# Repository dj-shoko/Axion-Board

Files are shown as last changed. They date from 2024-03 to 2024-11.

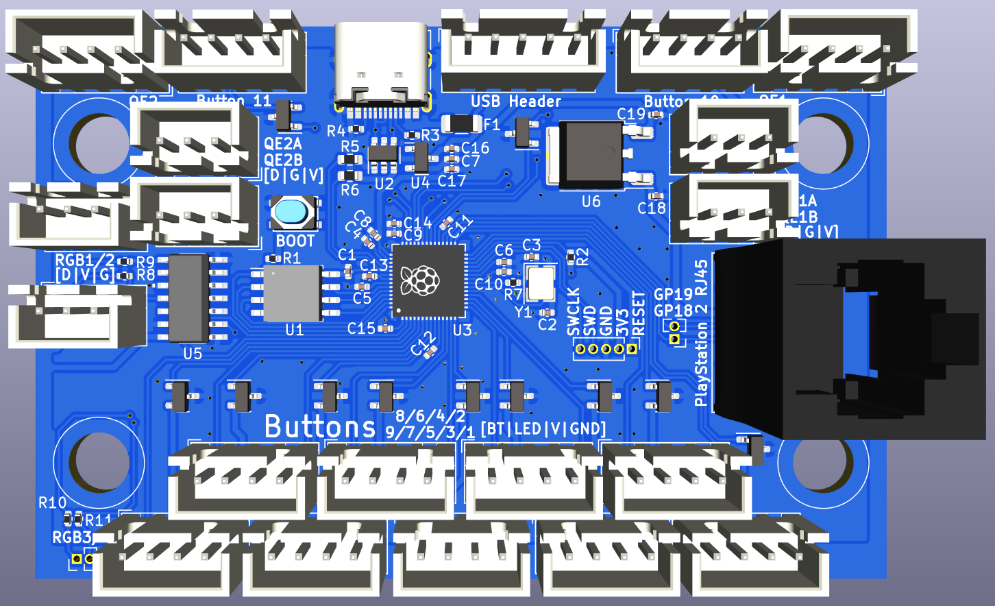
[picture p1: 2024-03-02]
images/render.png

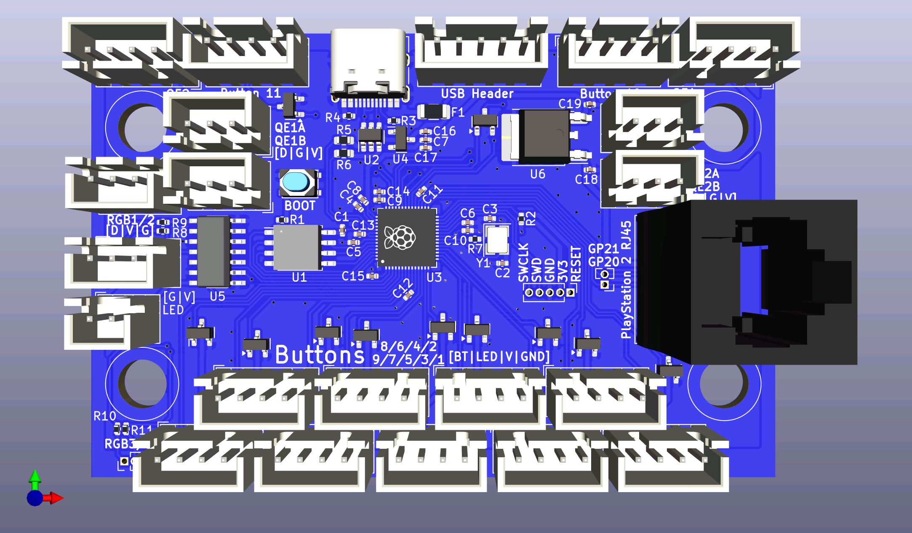
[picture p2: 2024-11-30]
images/render.jpg

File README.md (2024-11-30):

# Information
Fully functionally working PCB utilizing the RP2040 MCU with all GPIO pins broken out and able to be utilized. Main purpose of the board is for usage in beatmania IIDX and Sound Voltex controllers. The PCB can be dropped into DJ DAO based beatmania IIDX controllers as a drop in replacement, utilizing the same pin layout as their original PCBs. Main functionality allows for the usage of 11 buttons, 11 5V LEDs, 2 RGB pins, and 2 quadrature encoders (analog should also be accepted in theory due to those being hooked up to all 4 analog pins). PS2 support should be possible as well on the current PCB, but untested at the moment. Two extra pins are also available either for RGB or other general purposes if needed.

# Render and Schematics
- [Current board render](images/render.png)
- [Current board schematics](images/schematics.jpg)

# Credits
- [RP2040-designguide](https://github.com/Sleepdealr/RP2040-designguide/tree/main) to get started on the PCB designing aspects and schematics.
- [Pico Game Controller Firmware](https://github.com/speedypotato/Pico-Game-Controller) by SpeedyPotato for quick sanity check.
- [USBemani](https://github.com/progmem/usbemani) by Progmem for the current firmware I'm using for this board. Personally forked firmware UF2 files [here](https://github.com/dj-shoko/usbemani/releases).

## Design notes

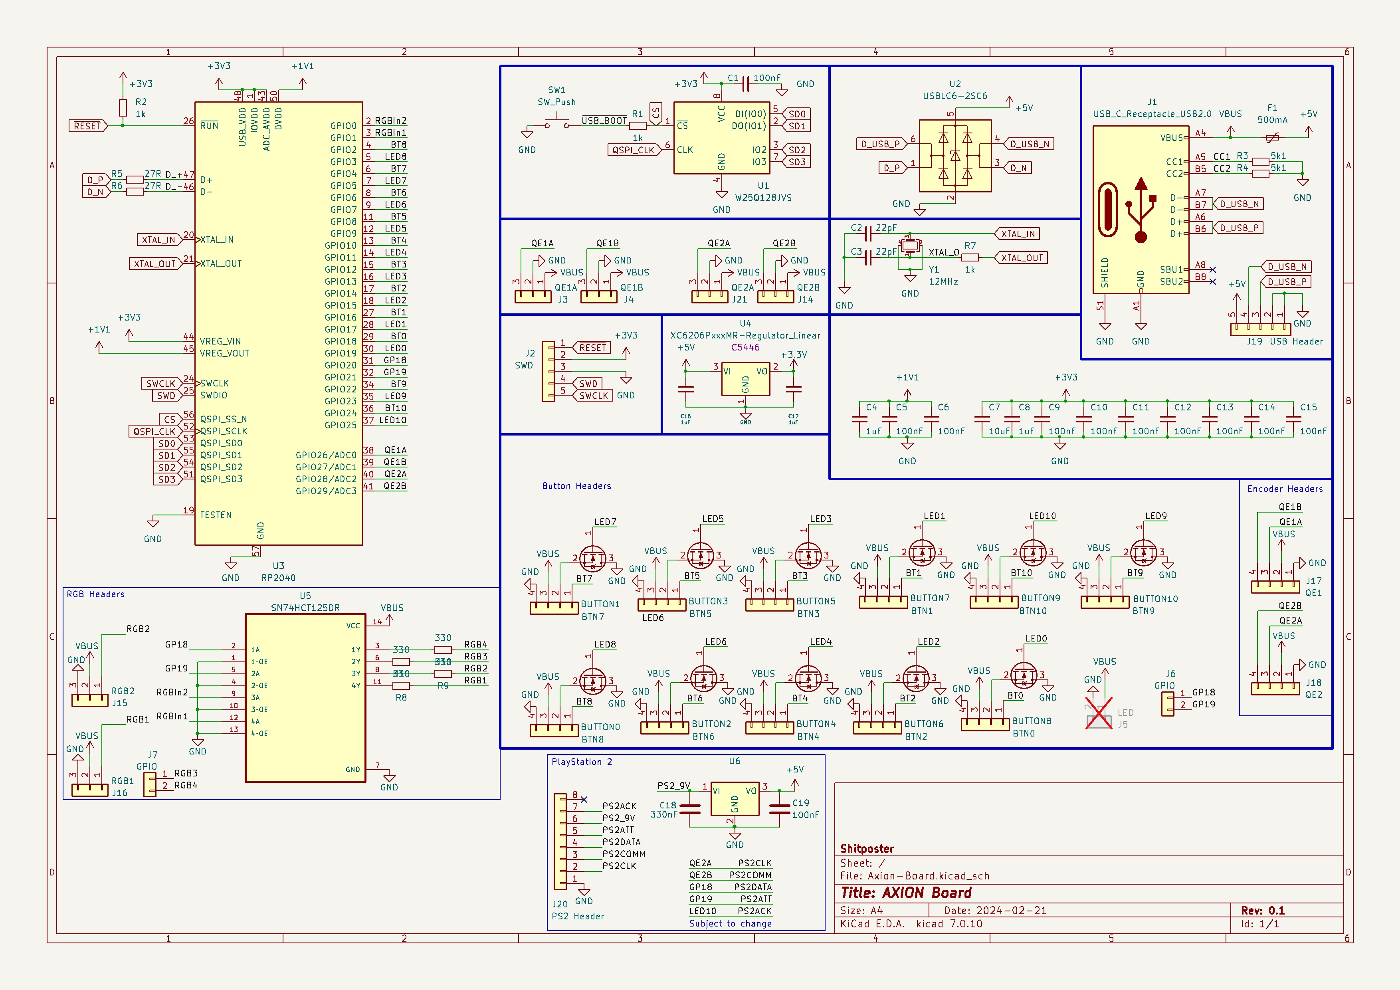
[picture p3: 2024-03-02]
images/schematics.jpg

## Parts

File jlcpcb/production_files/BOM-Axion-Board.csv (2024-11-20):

Comment | Designator | Footprint | LCSC
BSS138 | Q1,Q10,Q11,Q2,Q3,Q4,Q5,Q6,Q7,Q8,Q9 | SOT-23 | C112239
1k | R1,R2,R7 | R_0402_1005Metric | C11702
330 | R10,R11,R8,R9 | R_0402_1005Metric | C12246
W25Q128JVS | U1 | SOIC-8_5.23x5.23mm_P1.27mm | C131025
QE2B | J14,J15,J16,J21,J3,J4 | JST_XH_B3B-XH-A_1x03_P2.50mm_Vertical | C144394
BUTTON8 | BTN0,BTN1,BTN10,BTN2,BTN3,BTN4,BTN5,BTN6,BTN7,BTN8,BTN9,J17,J18 | JST_XH_B4B-XH-A_1x04_P2.50mm_Vertical | C144395
100nF | C1,C10,C11,C12,C13,C14,C15,C19,C5,C6,C9 | C_0402_1005Metric | C1525
10uF | C7 | C_0402_1005Metric | C15525
15pF | C2,C3 | C_0402_1005Metric | C1555
USB Header | J19 | JST_XH_B5B-XH-A_1x05_P2.50mm_Vertical | C157991
USB_C_Receptacle_USB2.0 | J1 | USB_C_Receptacle_HRO_TYPE-C-31-M-12 | C165948
RP2040 | U3 | RP2040-QFN-56 | C2040
SW_Push | SW1 | SW_SPST_PTS810 | C221895
27R | R5,R6 | R_0603_1608Metric | C25190
5k1 | R3,R4 | R_0402_1005Metric | C25905
USBLC6-2SC6 | U2 | SOT-23-6 | C2827654
PS2 Header | J20 | RJ45_OST_PJ012-8P8CX_Vertical | C2902702
330nF | C18 | C_0402_1005Metric | C307420
78M05_TO252-3 | U6 | TO-252-2 | C347278
SN74HCT125DR | U5 | SN74HCT125DR | C352957
1uF | C16,C17,C4,C8 | C_0402_1005Metric | C52923
XC6206PxxxMR-Regulator_Linear | U4 | SOT-23 | C5446
500mA | F1 | Fuse_1206_3216Metric | C70076
12MHz | Y1 | Crystal_SMD_3225-4Pin_3.2x2.5mm | C9002

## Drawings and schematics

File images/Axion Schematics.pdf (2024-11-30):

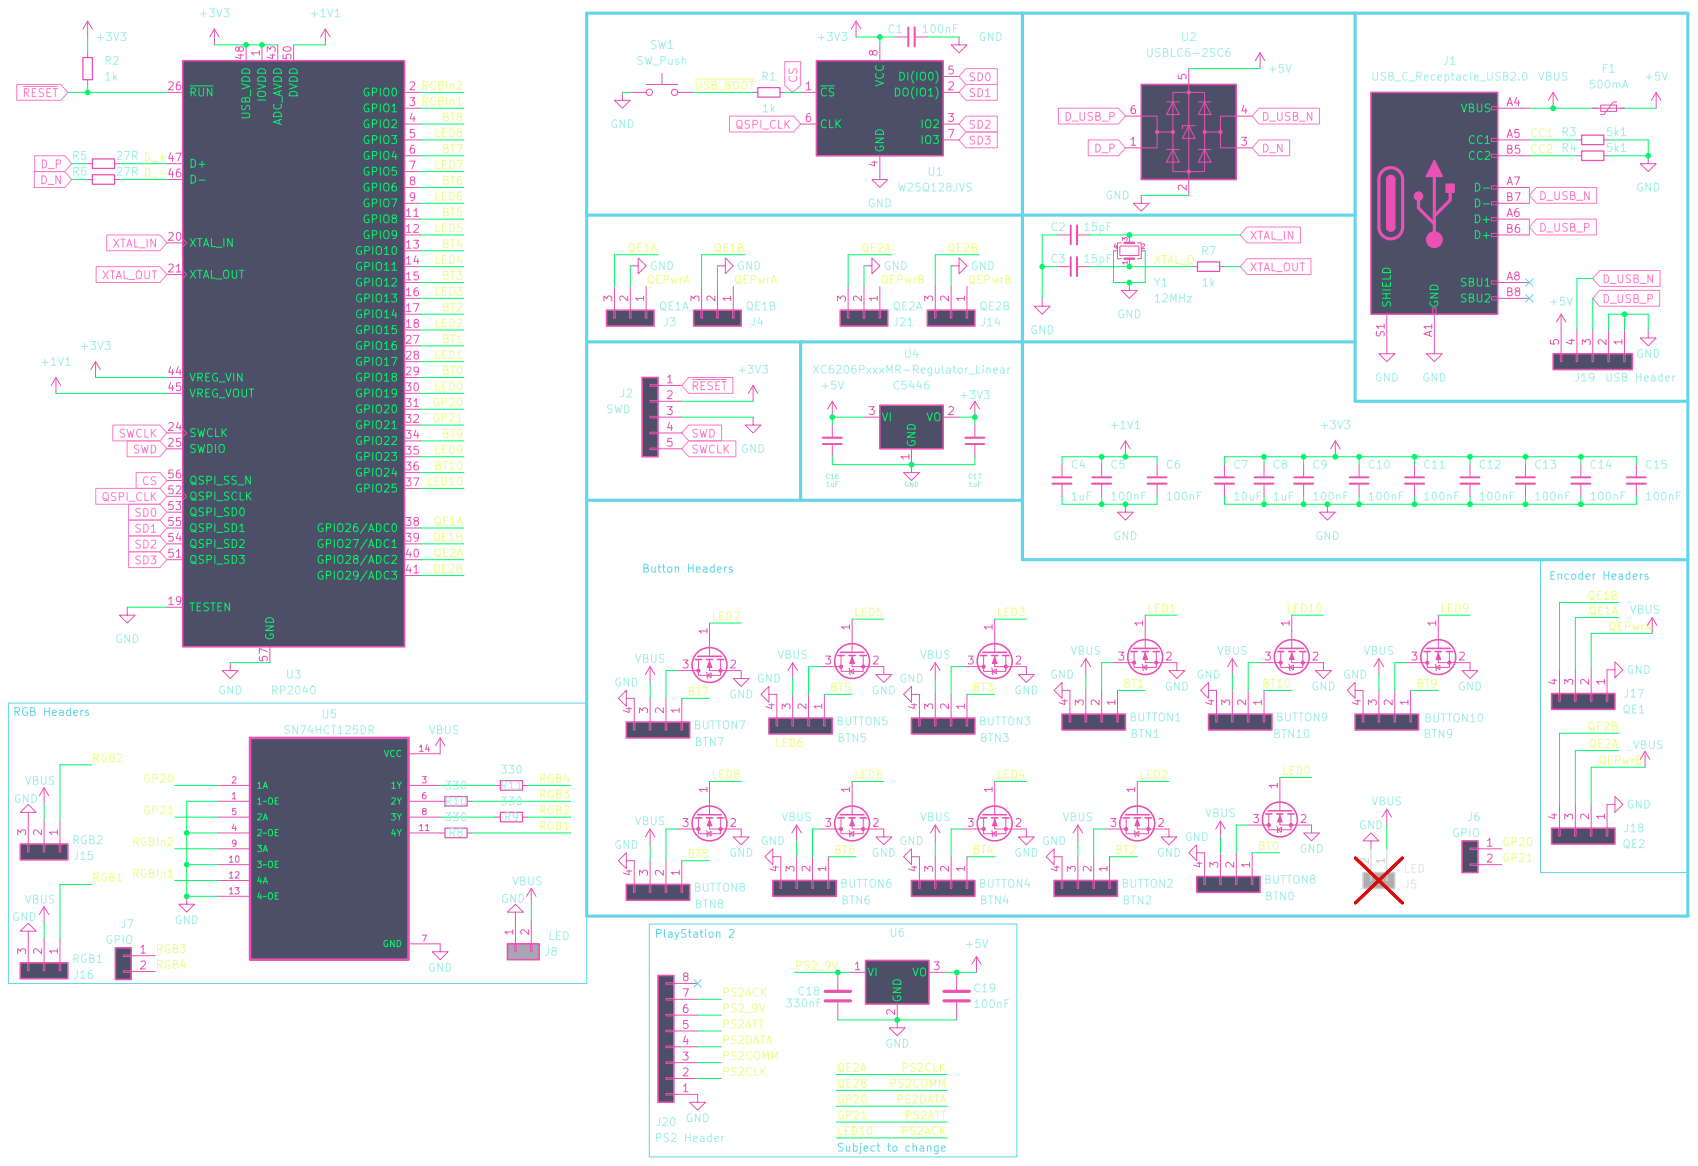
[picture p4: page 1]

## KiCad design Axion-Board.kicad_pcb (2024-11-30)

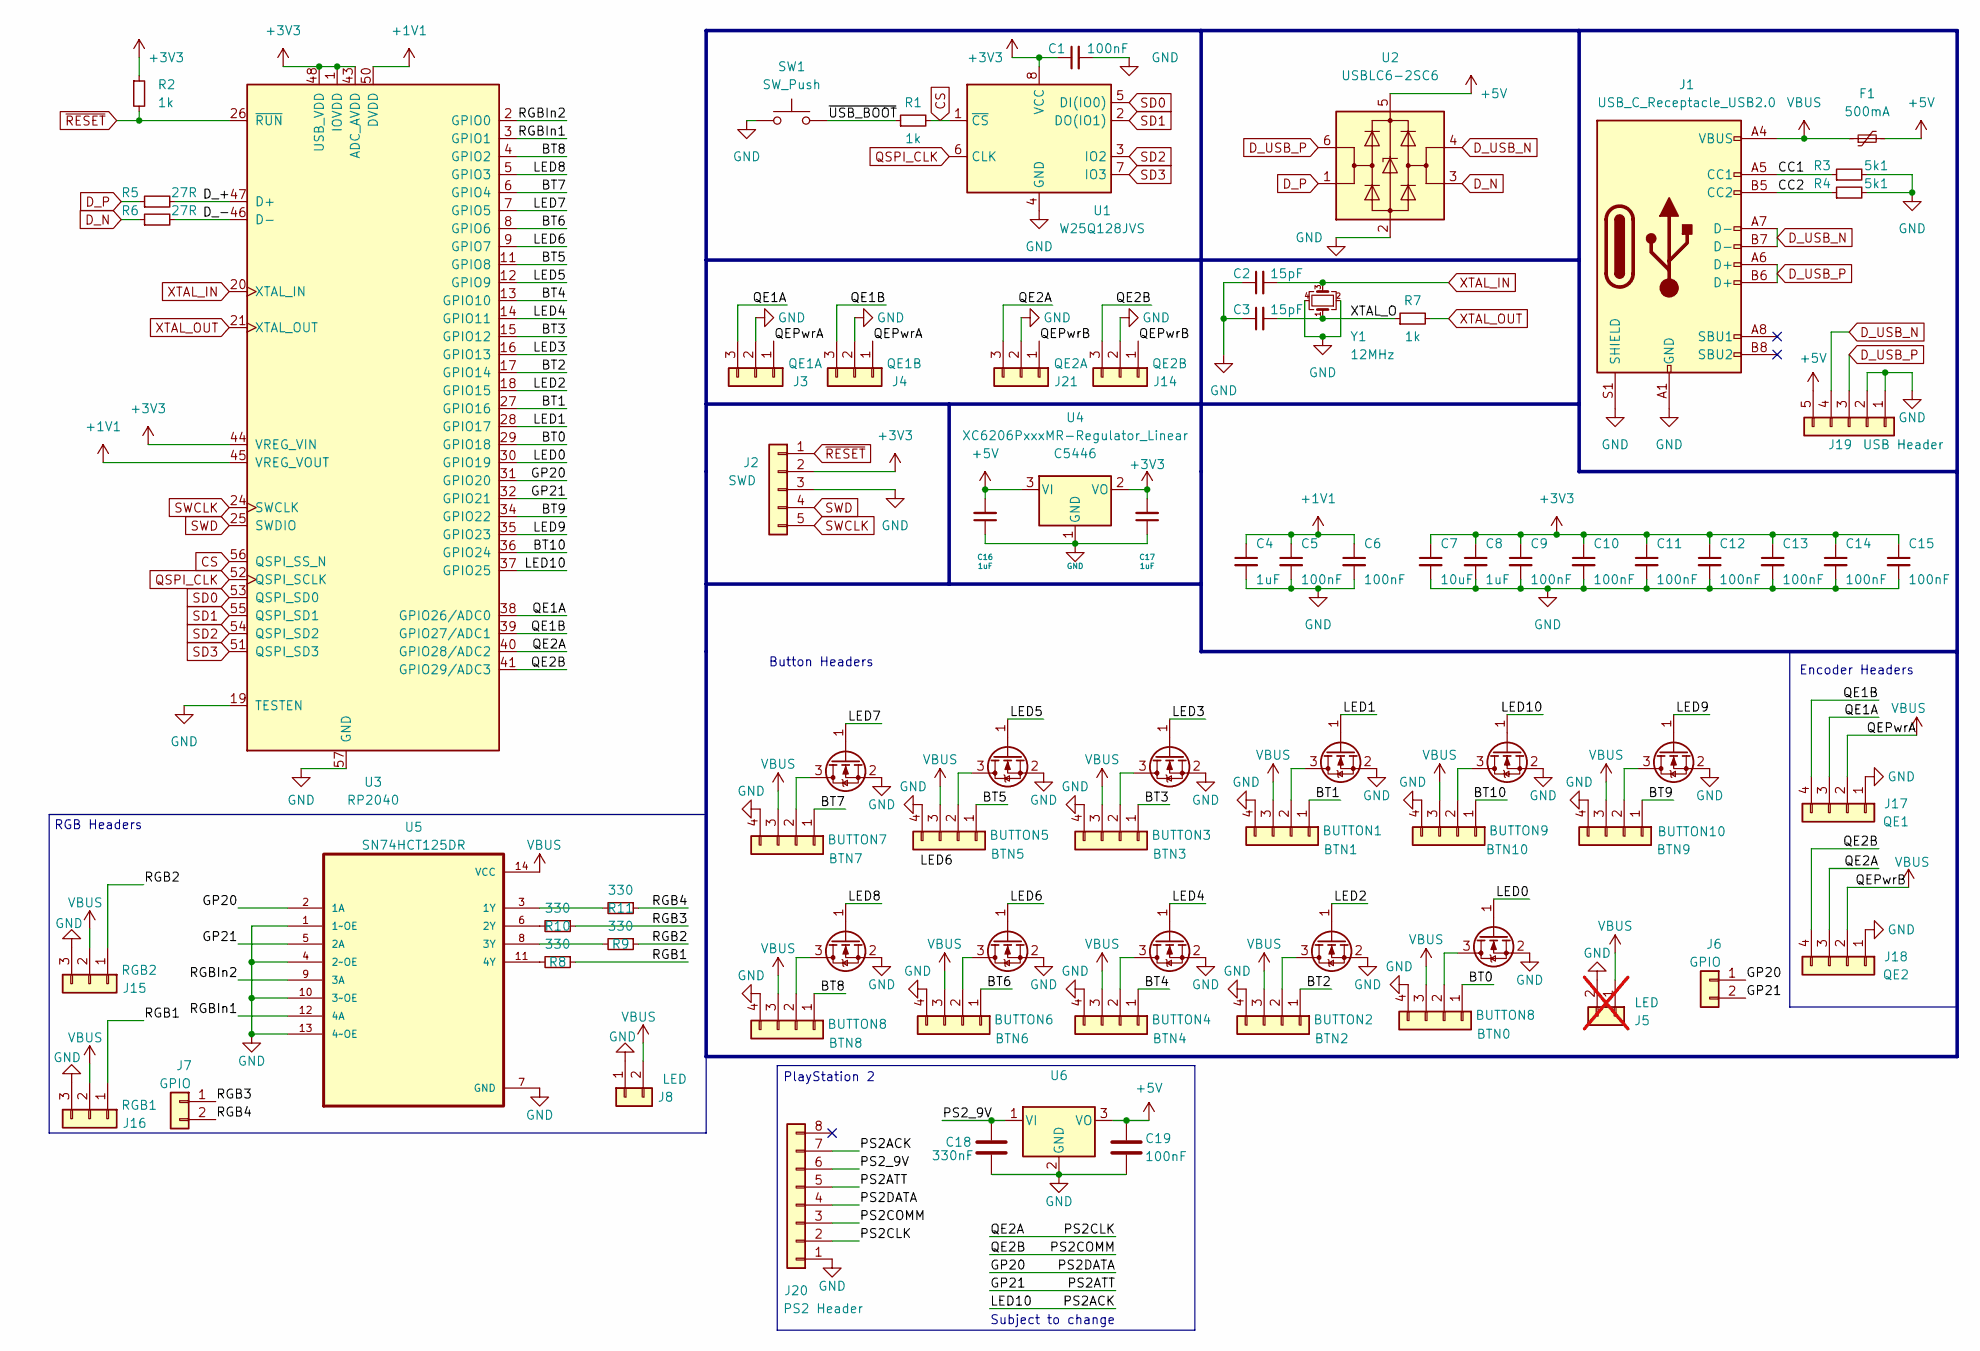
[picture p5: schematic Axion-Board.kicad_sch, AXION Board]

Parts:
BTN0, BTN8: BUTTON8; JST_XH_B4B-XH-A_1x04_P2.50mm_Vertical; LCSC C144395
BTN1: BUTTON1; JST_XH_B4B-XH-A_1x04_P2.50mm_Vertical; LCSC C144395
BTN2: BUTTON2; JST_XH_B4B-XH-A_1x04_P2.50mm_Vertical; LCSC C144395
BTN3: BUTTON3; JST_XH_B4B-XH-A_1x04_P2.50mm_Vertical; LCSC C144395
BTN4: BUTTON4; JST_XH_B4B-XH-A_1x04_P2.50mm_Vertical; LCSC C144395
BTN5: BUTTON5; JST_XH_B4B-XH-A_1x04_P2.50mm_Vertical; LCSC C144395
BTN6: BUTTON6; JST_XH_B4B-XH-A_1x04_P2.50mm_Vertical; LCSC C144395
BTN7: BUTTON7; JST_XH_B4B-XH-A_1x04_P2.50mm_Vertical; LCSC C144395
BTN9: BUTTON10; JST_XH_B4B-XH-A_1x04_P2.50mm_Vertical; LCSC C144395
BTN10: BUTTON9; JST_XH_B4B-XH-A_1x04_P2.50mm_Vertical; LCSC C144395
C1, C5, C6, C9, C10, C11, C12, C13, C14, C15, C19: 100nF; C_0402_1005Metric; LCSC C1525
C2, C3: 15pF; C_0402_1005Metric; LCSC C1555
C4, C8, C16, C17: 1uF; C_0402_1005Metric; LCSC C52923
C7: 10uF; C_0402_1005Metric; LCSC C15525
C18: 330nF; C_0402_1005Metric; LCSC C307420
F1: 500mA; Fuse_1206_3216Metric; LCSC C70076
J1: USB_C_Receptacle_USB2.0; USB_C_Receptacle_HRO_TYPE-C-31-M-12; LCSC C165948
J2: SWD; PinHeader_1x05_P1.27mm_Vertical
J3: QE1A; JST_XH_B3B-XH-A_1x03_P2.50mm_Vertical; LCSC C144394
J4: QE1B; JST_XH_B3B-XH-A_1x03_P2.50mm_Vertical; LCSC C144394
J5: LED; JST_XH_B2B-XH-A_1x02_P2.50mm_Vertical; LCSC C158012; not fitted
J6, J7: GPIO; PinHeader_1x02_P1.27mm_Vertical
J8: LED; JST_XH_B2B-XH-A_1x02_P2.50mm_Vertical; LCSC C158012
J14: QE2B; JST_XH_B3B-XH-A_1x03_P2.50mm_Vertical; LCSC C144394
J15: RGB2; JST_XH_B3B-XH-A_1x03_P2.50mm_Vertical; LCSC C144394
J16: RGB1; JST_XH_B3B-XH-A_1x03_P2.50mm_Vertical; LCSC C144394
J17: QE1; JST_XH_B4B-XH-A_1x04_P2.50mm_Vertical; LCSC C144395
J18: QE2; JST_XH_B4B-XH-A_1x04_P2.50mm_Vertical; LCSC C144395
J19: USB Header; JST_XH_B5B-XH-A_1x05_P2.50mm_Vertical; LCSC C157991
J20: PS2 Header; RJ45_OST_PJ012-8P8CX_Vertical; LCSC C2902702
J21: QE2A; JST_XH_B3B-XH-A_1x03_P2.50mm_Vertical; LCSC C144394
Q1, Q2, Q3, Q4, Q5, Q6, Q7, Q8, Q9, Q10, Q11: BSS138; SOT-23; LCSC C112239
R1, R2, R7: 1k; R_0402_1005Metric; LCSC C11702
R3, R4: 5k1; R_0402_1005Metric; LCSC C25905
R5, R6: 27R; R_0603_1608Metric; LCSC C25190
R8, R9, R10, R11: 330; R_0402_1005Metric; LCSC C12246
SW1: SW_Push; SW_SPST_PTS810; LCSC C221895
U1: W25Q128JVS; SOIC-8_5.23x5.23mm_P1.27mm; LCSC C131025
U2: USBLC6-2SC6; SOT-23-6; LCSC C2827654
U3: RP2040; RP2040-QFN-56; LCSC C2040
U4: XC6206PxxxMR-Regulator_Linear; SOT-23; LCSC C5446
U5: SN74HCT125DR; LCSC C352957
U6: 78M05_TO252-3; TO-252-2; LCSC C347278
Y1: 12MHz; Crystal_SMD_3225-4Pin_3.2x2.5mm; LCSC C9002

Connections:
+1V1: C4.1, C5.1, C6.1, U3.23 (DVDD), U3.45 (VREG_VOUT), U3.50 (DVDD)
+3V3: C1.1, C7.1, C8.1, C9.1, C10.1, C11.1, C12.1, C13.1, C14.1, C15.1, C17.2, J2.2, R2.1, U1.8 (VCC), U3.1 (IOVDD), U3.10 (IOVDD), U3.22 (IOVDD), U3.33 (IOVDD), U3.42 (IOVDD), U3.43 (ADC_AVDD), U3.44 (VREG_VIN), U3.48 (USB_VDD), U3.49 (IOVDD), U4.2 (VO)
+5V: C16.2, C19.1, F1.2, J19.5, U2.5 (VBUS), U4.3 (VI), U6.3 (VO)
/BT0: BTN0.1, U3.29 (GPIO18)
/BT1: BTN1.1, U3.27 (GPIO16)
/BT2: BTN2.1, U3.17 (GPIO14)
/BT3: BTN3.1, U3.15 (GPIO12)
/BT4: BTN4.1, U3.13 (GPIO10)
/BT5: BTN5.1, U3.11 (GPIO8)
/BT6: BTN6.1, U3.8 (GPIO6)
/BT7: BTN7.1, U3.6 (GPIO4)
/BT8: BTN8.1, U3.4 (GPIO2)
/BT9: BTN9.1, U3.34 (GPIO22)
/BT10: BTN10.1, U3.36 (GPIO24)
/CC1: J1.A5 (CC1), R3.1
/CC2: J1.B5 (CC2), R4.1
/D_+: R5.2, U3.47 (D+)
/D_-: R6.2, U3.46 (D-)
/GP20: J6.1, J20.4, U3.31 (GPIO20), U5.2 (1A)
/GP21: J6.2, J20.5, U3.32 (GPIO21), U5.5 (2A)
/LED0: Q5.1 (G), U3.30 (GPIO19)
/LED1: Q8.1 (G), U3.28 (GPIO17)
/LED2: Q4.1 (G), U3.18 (GPIO15)
/LED3: Q9.1 (G), U3.16 (GPIO13)
/LED4: Q2.1 (G), U3.14 (GPIO11)
/LED5: Q10.1 (G), U3.12 (GPIO9)
/LED6: Q1.1 (G), U3.9 (GPIO7)
/LED7: Q11.1 (G), U3.7 (GPIO5)
/LED8: Q3.1 (G), U3.5 (GPIO3)
/LED9: Q6.1 (G), U3.35 (GPIO23)
/LED10: J20.7, Q7.1 (G), U3.37 (GPIO25)
/PS2CLK: J18.3, J20.2, J21.3, U3.40 (GPIO28/ADC2)
/PS2COMM: J14.3, J18.4, J20.3, U3.41 (GPIO29/ADC3)
/PS2_9V: C18.1, J20.6, U6.1 (VI)
/QE1A: J3.3, J17.3, U3.38 (GPIO26/ADC0)
/QE1B: J4.3, J17.4, U3.39 (GPIO27/ADC1)
/RGB1: J16.1, R8.1
/RGB2: J15.1, R9.1
/RGB3: J7.1, R10.1
/RGB4: J7.2, R11.1
/RGBIn1: U3.3 (GPIO1), U5.12 (4A)
/RGBIn2: U3.2 (GPIO0), U5.9 (3A)
/XTAL_O: C3.2, R7.1, Y1.1
/~USB_BOOT: R1.1, SW1.2
CS: R1.2, U1.1 (~CS), U3.56 (QSPI_SS_N)
D_N: R6.1, U2.3 (I/O2)
D_P: R5.1, U2.1 (I/O1)
D_USB_N: J1.A7 (D-), J1.B7 (D-), J19.4, U2.4 (I/O2)
D_USB_P: J1.A6 (D+), J1.B6 (D+), J19.3, U2.6 (I/O1)
GND: BTN0.4, BTN1.4, BTN2.4, BTN3.4, BTN4.4, BTN5.4, BTN6.4, BTN7.4, BTN8.4, BTN9.4, BTN10.4, C1.2, C2.1, C3.1, C4.2, C5.2, C6.2, C7.2, C8.2, C9.2, C10.2, C11.2, C12.2, C13.2, C14.2, C15.2, C16.1, C17.1, C18.2, C19.2, J1.A1 (GND), J1.A12 (GND), J1.S1 (SHIELD), J2.3, J3.2, J4.2, J5.2, J8.1, J14.2, J15.3, J16.3, J17.1, J18.1, J19.1, J19.2, J20.1, J21.2, Q1.2 (S), Q2.2 (S), Q3.2 (S), Q4.2 (S), Q5.2 (S), Q6.2 (S), Q7.2 (S), Q8.2 (S), Q9.2 (S), Q10.2 (S), Q11.2 (S), R3.2, R4.2, SW1.1, U1.4 (GND), U2.2 (GND), U3.19 (TESTEN), U3.57 (GND), U4.1 (GND), U5.1 (1~OE), U5.4 (2~OE), U5.7 (GND), U5.10 (3~OE), U5.13 (4~OE), U6.2 (GND), Y1.2, Y1.4; also elsewhere on the board
unnamed: BTN0.2, Q5.3 (D)
unnamed: BTN1.2, Q8.3 (D)
unnamed: BTN2.2, Q4.3 (D)
unnamed: BTN3.2, Q9.3 (D)
unnamed: BTN4.2, Q2.3 (D)
unnamed: BTN5.2, Q10.3 (D)
unnamed: BTN6.2, Q1.3 (D)
unnamed: BTN7.2, Q11.3 (D)
unnamed: BTN8.2, Q3.3 (D)
unnamed: BTN9.2, Q6.3 (D)
unnamed: BTN10.2, Q7.3 (D)
unnamed: R11.2, U5.3 (1Y)
unnamed: R10.2, U5.6 (2Y)
unnamed: R9.2, U5.8 (3Y)
unnamed: R8.2, U5.11 (4Y)
QSPI_CLK: U1.6 (CLK), U3.52 (QSPI_SCLK)
SD0: U1.5 (DI(IO0)), U3.53 (QSPI_SD0)
SD1: U1.2 (DO(IO1)), U3.55 (QSPI_SD1)
SD2: U1.3 (IO2), U3.54 (QSPI_SD2)
SD3: U1.7 (IO3), U3.51 (QSPI_SD3)
SWCLK: J2.5, U3.24 (SWCLK)
SWD: J2.4, U3.25 (SWDIO)
VBUS: BTN0.3, BTN1.3, BTN2.3, BTN3.3, BTN4.3, BTN5.3, BTN6.3, BTN7.3, BTN8.3, BTN9.3, BTN10.3, F1.1, J1.A4 (VBUS), J1.A9 (VBUS), J1.B4 (VBUS), J1.B9 (VBUS), J3.1, J4.1, J5.1, J8.2, J14.1, J15.2, J16.2, J17.2, J18.2, J21.1, U5.14 (VCC); also elsewhere on the board
XTAL_IN: C2.2, U3.20 (XTAL_IN), Y1.3
XTAL_OUT: R7.2, U3.21 (XTAL_OUT)
~RESET: J2.1, R2.2, U3.26 (~RUN)

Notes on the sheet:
Button Headers
PlayStation 2
RGB Headers
Subject to change
Encoder Headers

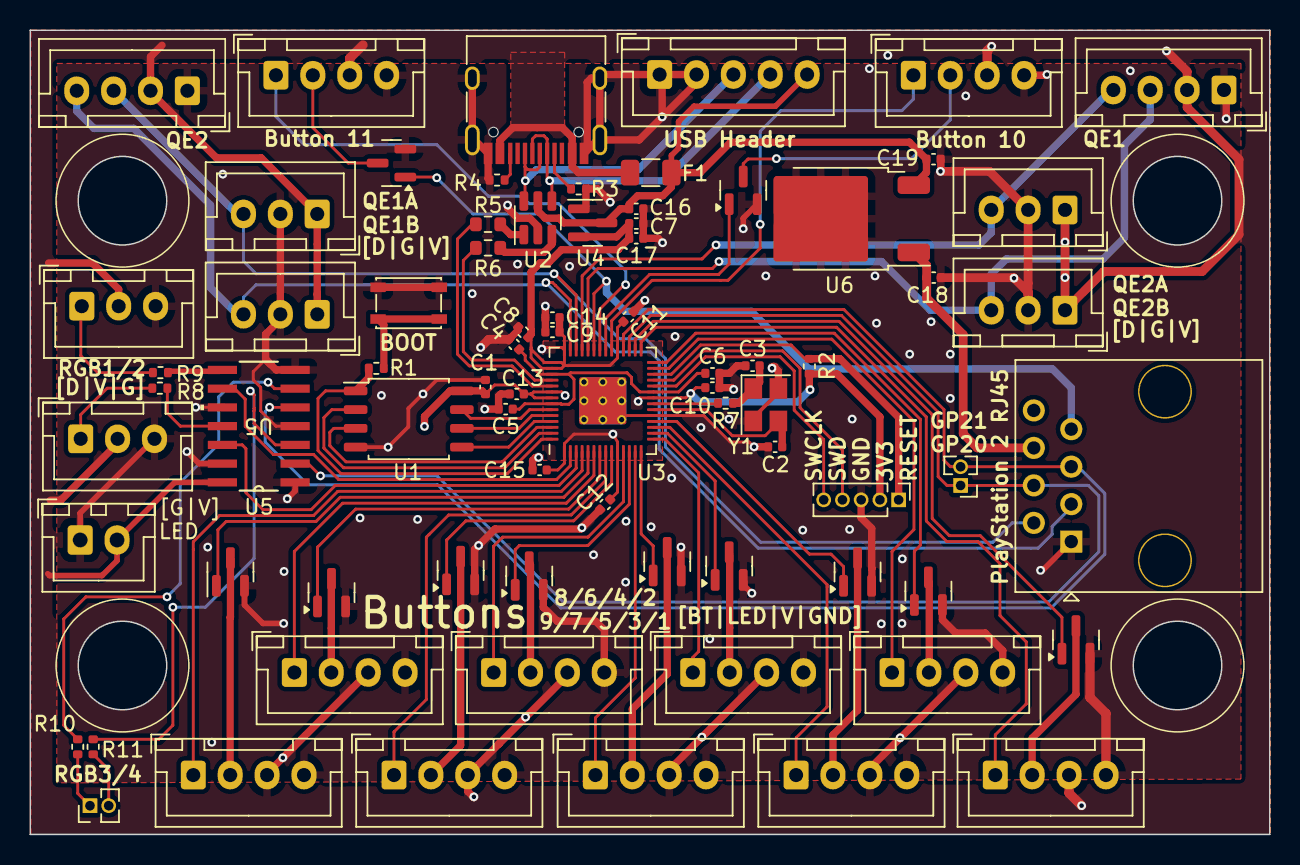
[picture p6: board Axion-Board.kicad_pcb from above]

Board: 2 copper layers, 84.0 x 54.5 mm, 76 parts (0 on the bottom side), 76 nets.

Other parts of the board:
LED: LED; JST_XH_B2B-XH-A_1x02_P2.50mm_Vertical

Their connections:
GND: LED.1; also elsewhere on the board
VBUS: LED.2; also elsewhere on the board

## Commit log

2023-06-25 Add files via upload
    Initial commit
    [RhythmGamePicoBreakout.kicad_pcb, RhythmGamePicoBreakout.kicad_sch]
2023-06-30 Updated Schematics and PCB design
    [RhythmGamePicoBreakout.kicad_pcb, RhythmGamePicoBreakout.kicad_sch]
2023-06-30 Updated Schematics image and PCB render
2023-07-01 Updated schematics and completely redone tracing
    [RhythmGamePicoBreakout.kicad_pcb, RhythmGamePicoBreakout.kicad_sch]
2023-07-01 Completely redid the traces
    [RhythmGamePicoBreakout.kicad_pcb]
2024-03-02 Redid entire board and renamed project.
    [Axion-Board-CuBottom.gbr, Axion-Board-CuTop.gbr, Axion-Board-EdgeCuts.gbr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]
2024-11-20 Fixed the mosfet wiring
    [Axion-Board.kicad_pcb, Axion-Board.kicad_sch]
2024-11-20 Updated JLCPCB files
    [BOM-Axion-Board.csv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]
2024-11-20 Latest JLCPCB Gerber Files
    [Axion-Board-CuBottom.gbr, Axion-Board-CuTop.gbr, Axion-Board-EdgeCuts.gbr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]
2024-11-30 Added turntable LED header
2024-11-30 Added turntable LED header with BOM part
    [Axion-Board.kicad_pcb, Axion-Board.kicad_sch]
